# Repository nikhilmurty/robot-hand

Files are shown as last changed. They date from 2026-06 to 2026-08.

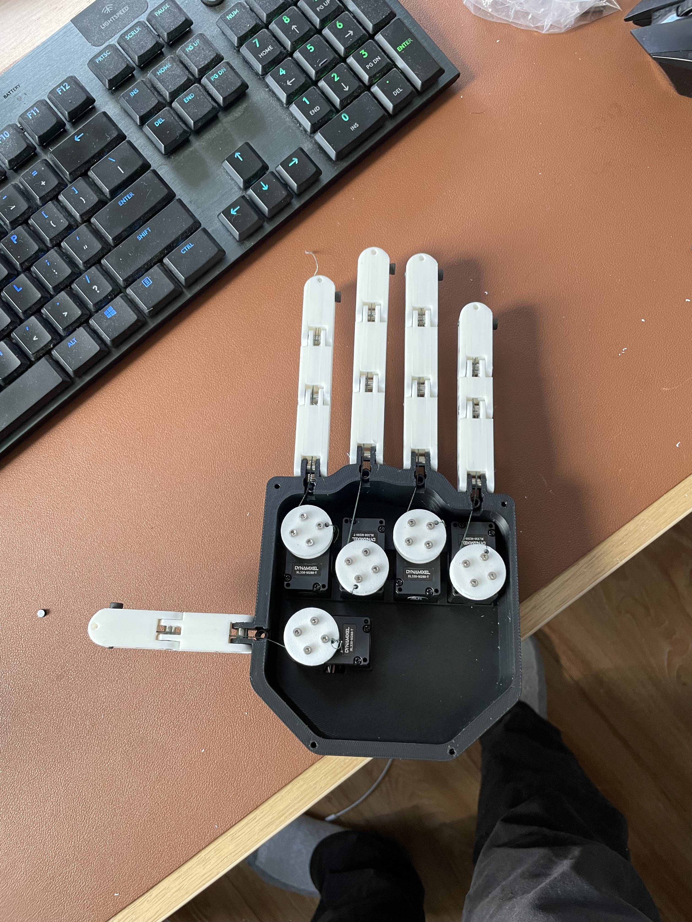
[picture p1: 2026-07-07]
hardware/IMG_2481.jpeg

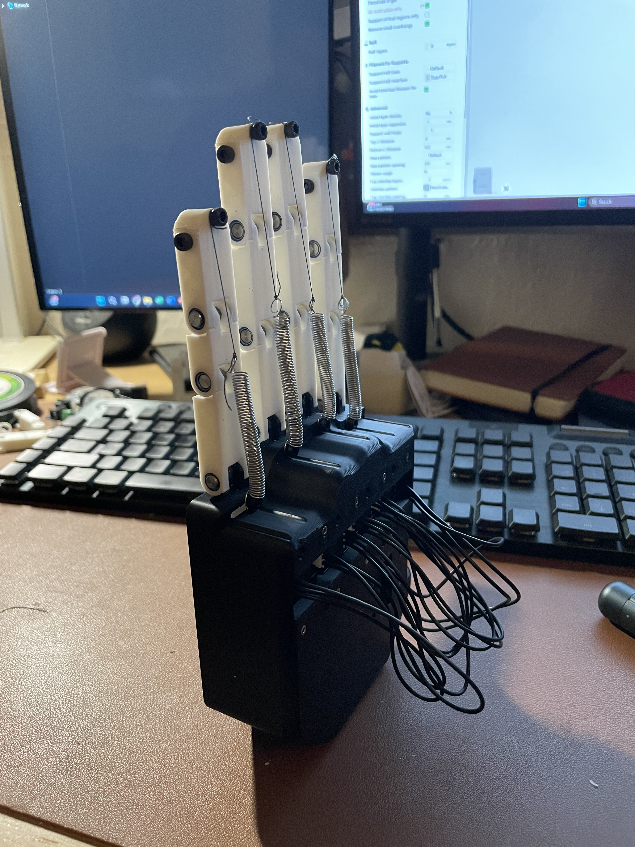
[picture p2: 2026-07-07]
hardware/IMG_2484.jpeg

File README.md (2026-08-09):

# Robot Hand

This repository contains the design, CAD models, and control software for a 5-DOF tension-driven robotic hand controlled via live webcam hand tracking.

## Quick Start Overview

To run this project, you will need to:
1. **Connect & Configure Hardware**:
   - Connect **5x Dynamixel XL-330 motors** to an **OpenRB-150** controller board (flashed with USB Passthrough / `usb_to_dxl` firmware).
   - Use **ROBOTIS DYNAMIXEL Wizard 2.0** to set baud rate to `57600` and assign motor IDs `1` (Pinky), `2` (Ring), `3` (Middle), `4` (Pointer), `5` (Thumb).
   - For detailed assembly instructions, see [hardware/README.md](hardware/README.md).

2. **Configure & Run Software**:
   - Install Python dependencies (`uv sync` or `pip install -r ...`).
   - Verify/update the serial port (`DEVICENAME`) in `software/hand_controller.py` (e.g. `COM7`, `/dev/ttyACM0`, or `/dev/tty.usbmodem*`).
   - Run the main capture script:
     ```bash
     uv run python software/finger_capture.py
     ```
   - For detailed setup, auto-tensioning overview, and software architecture, see [software/README.md](software/README.md).

## Repository Structure

- **[hardware/](hardware/README.md)**: 3D CAD files (STEP, 3MF), bill of materials, Onshape link, and hardware assembly guide. Licensed under CERN OHL v2 Permissive.
- **[software/](software/README.md)**: Python scripts for MediaPipe hand tracking (`finger_capture.py`) and Dynamixel servo control (`hand_controller.py`).

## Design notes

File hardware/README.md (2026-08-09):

# Hardware

This folder contains all the 3D design and print files for the robot hand and fingers. View the full 3D assembly on [Onshape](https://cad.onshape.com/documents/e974f0bc1062bd7b6ade647d/w/e4fd7f55056d36383327a202/e/fd9bded8c1b01162ac553002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).

## Parts & Bill of Materials

To build the hardware setup, you will need:

- **5x Dynamixel XL-330 motors**
- **1x ROBOTIS OpenRB-150 controller board** (serves as the USB-to-Dynamixel communication bridge)
- **1x USB-C Cable** (to connect OpenRB-150 to your host PC)
- **1x 5V Power Supply / Terminal block** (to power the Dynamixel motors via the OpenRB-150 board)
- **1x USB Camera / Webcam** (for hand tracking)
- **30x Bearings** (5mm ID, 8mm OD, e.g. MR85-2RS)
- **15x Dowel Pins** (M5 x 14mm)
- **Durable Cable / String** (e.g. 40 lbs braided fishing line for tendon control)
- **5x Springs** (0.5 x 5.5 x 35.5 mm for finger return tensioning)
- **Assorted M2 and M3 Screws and nuts** (I bought sets of these on amazon)
- **M2 and M3 Tap** (M2 for tapping holes in the dynamixels and M3 for the hand)

---

## Hardware Configuration & Wiring

### 1. OpenRB-150 Controller Board
- Connect the **OpenRB-150** to your computer via USB-C.
- Ensure the OpenRB-150 is flashed with **USB Passthrough firmware** (such as `usb_to_dxl` from the OpenRB-150 / DYNAMIXEL library in Arduino IDE) so it functions as a serial bridge between your computer and the servos.

### 2. Dynamixel Motor ID & Baud Rate Configuration
Use **ROBOTIS DYNAMIXEL Wizard 2.0** to assign IDs and set the baud rate before assembling:
- **Baud Rate**: `57600` (all motors must match)
- **Motor IDs**:
  - `ID 1`: Pinky Finger
  - `ID 2`: Ring Finger
  - `ID 3`: Middle Finger
  - `ID 4`: Pointer (Index) Finger
  - `ID 5`: Thumb

### 3. Assembly & Wiring
- Daisy-chain or plug all 5 Dynamixel XL-330 motors into the TTL 3-pin ports on the OpenRB-150.
- Mount the motors to the spools in the main palm assembly.
- Route string through finger joint channels and secure to tensioning springs as detailed in the Onshape model.

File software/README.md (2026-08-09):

# Software

This directory contains the Python software to control the 5-DOF tension-driven robotic hand using live webcam hand landmark tracking.

## Prerequisites

### 1. Hardware Requirements
- **Webcam**: Standard USB camera connected to your host PC.
- **OpenRB-150 Controller Board**: Connected via USB and configured with USB passthrough firmware (`usb_to_dxl`).
- **5x Dynamixel XL-330 Motors**: Connected to the OpenRB-150 board and configured as follows:
  - **Baudrate**: `57600`
  - **IDs**: 1 (Pinky), 2 (Ring), 3 (Middle), 4 (Pointer), 5 (Thumb)

### 2. Software Requirements
- **Python**: Version `3.12+`
- **Dependencies**:
  - `dynamixel-sdk`
  - `mediapipe`
  - `opencv-python`
  - `numpy`

---

## Installation & Setup

1. **Install Dependencies** using `uv` (recommended) or `pip`:
   ```bash
   uv sync
   ```
   *Alternatively, using standard `pip`:*
   ```bash
   pip install dynamixel-sdk mediapipe opencv-python numpy
   ```

2. **Identify Your Serial Port**:
   Check which port the OpenRB-150 is mounted on:
   - **Windows**: `COM3`, `COM7`, etc.
   - **macOS**: `/dev/tty.usbmodem*` or `/dev/cu.usbmodem*`
   - **Linux**: `/dev/ttyACM0` or `/dev/ttyUSB0`

3. **Configure the Serial Port**:
   In `software/hand_controller.py`, ensure the default `DEVICENAME` matches your system's serial port:
   ```python
   # Example in software/hand_controller.py:
   def __init__(self, DEVICENAME='COM7'): # Change 'COM7' to your device port (e.g. '/dev/ttyACM0')
   ```

---

## How to Run

Run `finger_capture.py` to start the hand tracking and control system:

```bash
uv run python software/finger_capture.py
```
*(or `python software/finger_capture.py` if using standard Python virtual environment)*

---

## What Happens When Running `finger_capture.py`

1. **Camera & Landmarker Setup**: Initializes OpenCV video capture from webcam (Device 0) and loads the MediaPipe `hand_landmarker.task` model.
2. **Auto-Tensioning Sequence**: 
   - `HandController` initializes the OpenRB-150 connection.
   - Executes `auto_tension()` across all 5 Dynamixels (IDs 1 through 5).
   - Servos pull tension until current limits are detected to establish the open/closed position bounds for each finger.
3. **Live Hand Tracking & Motor Control**:
   - A thread reads frames from the webcam and runs MediaPipe hand landmark detection.
   - A second thread extracts 3D joint vectors for each finger (thumb, pointer, middle, ring, pinky) to compute flexion angles.
   - Angles are transformed into motor target positions and synced over the serial port to the OpenRB-150 board.
4. **Display & Exit**:
   - Displays a live video feed window with skeleton landmark overlays.
   - Press **`q`** while focused on the video window to quit, disable motor torque, and safely close the serial connection.

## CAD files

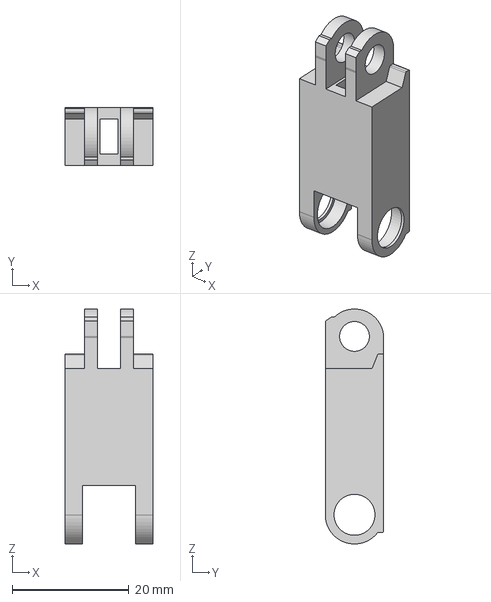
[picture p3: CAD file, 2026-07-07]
hardware/ Index/Index - Middle_Segment.step
15.0 x 10.0 x 40.2 mm

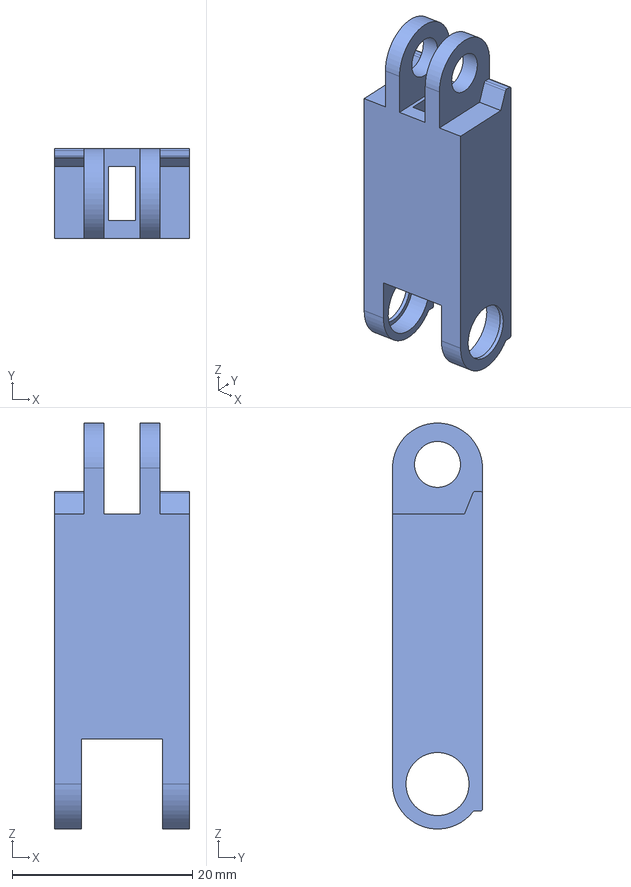
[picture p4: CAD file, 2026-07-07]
hardware/Middle/Middle - Bottom_Segment.step
15.0 x 10.0 x 45.1 mm

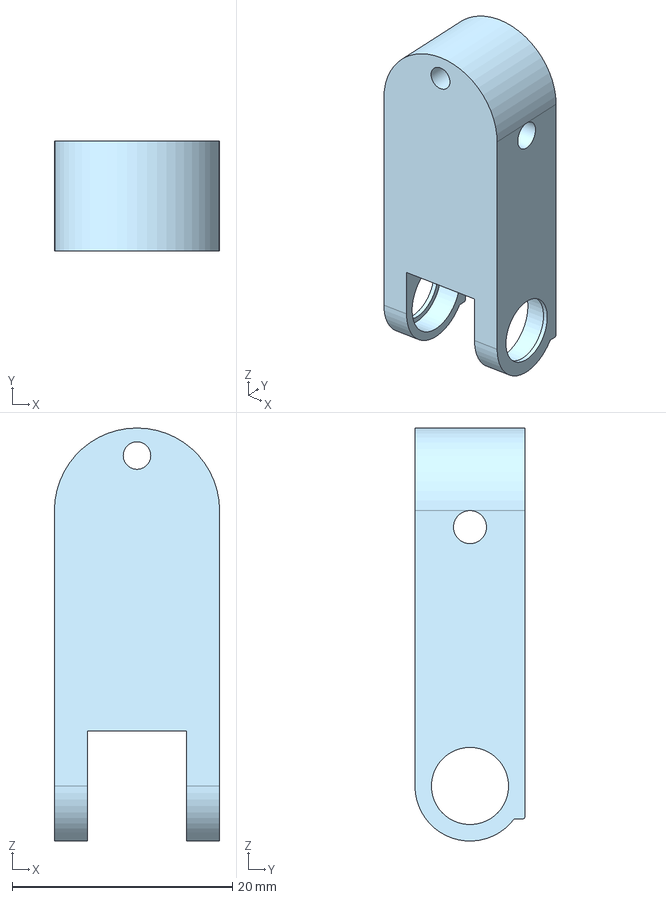
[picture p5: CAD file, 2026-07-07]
hardware/Ring/Ring - Top_Segment.step
15.0 x 10.0 x 37.5 mm

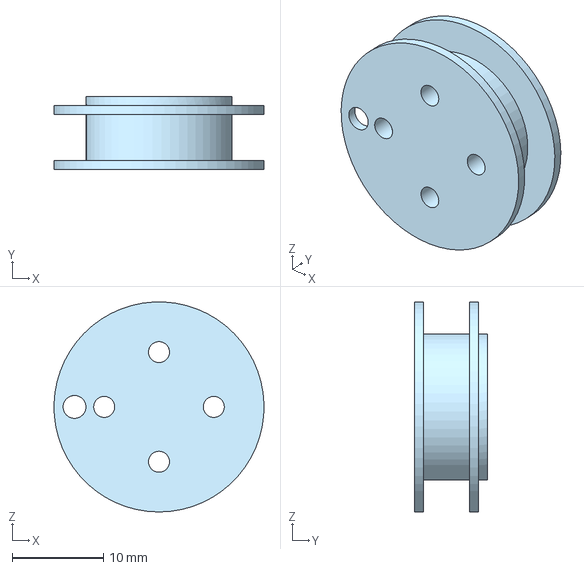
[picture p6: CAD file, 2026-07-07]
hardware/Spool.step
23.0 x 8.00 x 23.0 mm

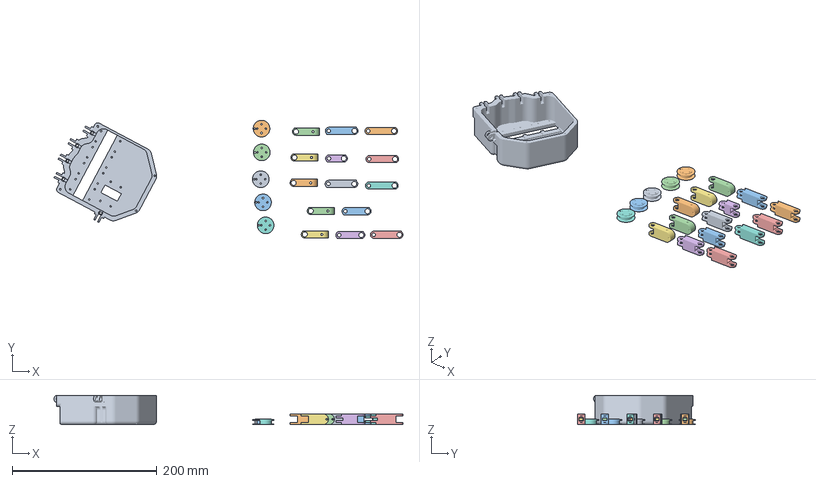
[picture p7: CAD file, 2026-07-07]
hardware/Hand.3mf
481.7 x 163.4 x 40.5 mm
Palm - Palm.step
Middle - Bottom_Segment.step
Middle - Middle_Segment.step
Middle - Top_Segment.step
Pinky - Bottom_Segment.step
Pinky - Middle_Segment.step
Pinky - Top_Segment.step
Ring - Bottom_Segment.step
Ring - Middle_Segment.step
Ring - Top_Segment.step
Thumb - Middle_Segment.step
Thumb - Top_Segment.step
Index - Bottom_Segment.step
Index - Middle_Segment.step
Index - Top_Segment.step
Spool.step x 5

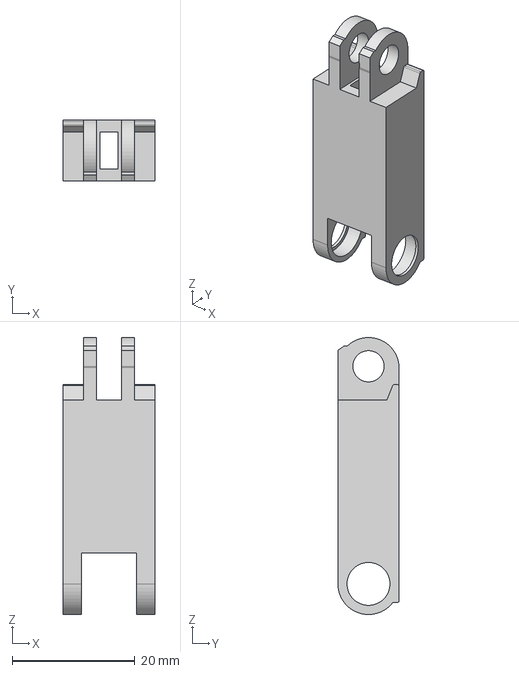
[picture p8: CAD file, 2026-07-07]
hardware/Middle/Middle - Middle_Segment.step
15.0 x 10.0 x 45.2 mm

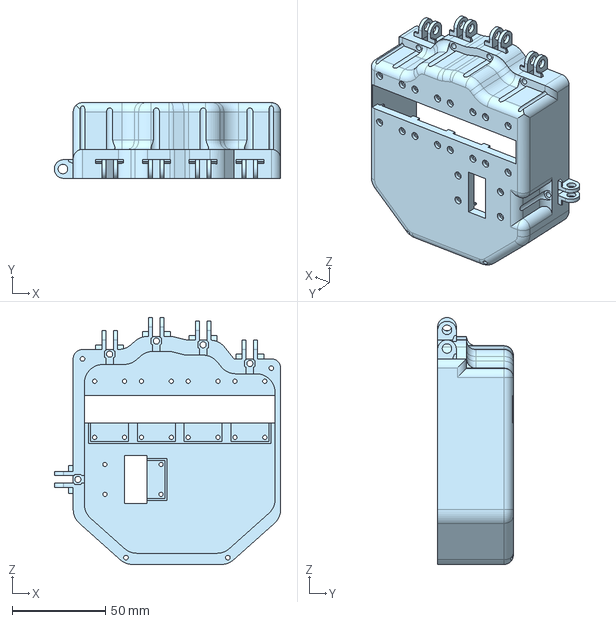
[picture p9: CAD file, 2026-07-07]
hardware/Palm - Palm.step
121.1 x 40.5 x 132.1 mm

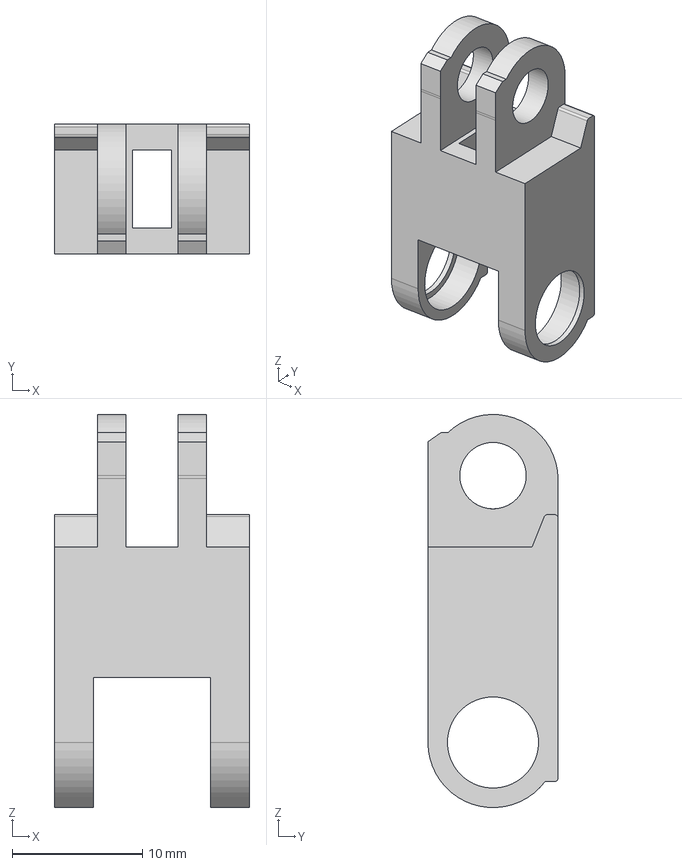
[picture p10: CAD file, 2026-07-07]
hardware/Pinky/Pinky - Middle_Segment.step
15.0 x 10.0 x 30.2 mm

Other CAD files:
hardware/Pinky/Pinky - Bottom_Segment.step
hardware/Thumb/Thumb - Top_Segment.step
hardware/ Index/Index - Top_Segment.step
hardware/Pinky/Pinky - Top_Segment.step
hardware/Ring/Ring - Bottom_Segment.step
hardware/Thumb/Thumb - Middle_Segment.step
hardware/ Index/Index - Bottom_Segment.step
hardware/Middle/Middle - Top_Segment.step
hardware/Ring/Ring - Middle_Segment.step

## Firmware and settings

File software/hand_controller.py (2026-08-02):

"""Hand Controller Class
Handles control of 5 dynamixel motors that control the fingers on a tension driven robotic hand
"""
from dynamixel_sdk import *
import time
import threading

class Finger:
    def __init__(self, name, motor_id, min = 0, max = 120):
        self.name = name
        self.motor_id = motor_id
        self.open_pos = 0
        self.closed_pos = 0

        self.min_angle = min
        self.max_angle = max

        self.actual_pos = 0.0
        self.actual_current = 0.0
        self.actual_velocity = 0.0

        self.target_pos = 0


    def calculate_motor_angle(self, finger_angle):
        # Clamp input to safe bounds
        clamped_angle = max(self.min_angle, min(finger_angle, self.max_angle))
        
        # Map from [min, max] -> [closed, open]
        self.target_pos = self.open_pos + (clamped_angle - self.min_angle) * (self.closed_pos - self.open_pos) / (self.max_angle - self.min_angle)
        return int(self.target_pos)
    
    def update_values(self, pos, current, velocity):
        self.actual_pos = pos
        self.actual_current = current
        self.actual_velocity = velocity


class HandController:
    ADDR_TORQUE_ENABLE          = 64
    ADDR_OPERATING_MODE         = 11          
    ADDR_TARGET_POSITION        = 116
    ADDR_GOAL_CURRENT           = 102
    LEN_GOAL_POSITION           = 4

    ADDR_ACTUAL_POSITION        = 132
    ADDR_ACTUAL_CURRENT         = 126
    ADDR_ACTUAL_VELOCITY        = 128

    CURRENT_POSITION_OPERATION  = 5         #Current based position
    MAX_CURRENT                 = 300       #current cap until backdrivable
    TENSION_CURRENT             = 20

    PROTOCOL_VERSION            = 2.0
    DXL_ID                      = 1
    BAUDRATE                    = 57600

    THUMB                       = 5
    POINTER                     = 4
    MIDDLE                      = 3
    RING                        = 2
    PINKY                       = 1
    MOTOR_IDS                   = [1,2,3,4,5]


    def __init__(self, DEVICENAME ='COM7'):
        self.portHandler = PortHandler(DEVICENAME)
        self.packetHandler = PacketHandler(self.PROTOCOL_VERSION)

        if not self.portHandler.openPort() or not self.portHandler.setBaudRate(self.BAUDRATE):
            print("Failed to open port or set baudrate. Check your DEVICENAME!")
            quit()

        #create the hand
        self.hand = {
            "THUMB"   : Finger("THUMB", self.THUMB, 0, 75),
            "POINTER" : Finger("POINTER", self.POINTER, 0, 120),
            "MIDDLE"  : Finger("MIDDLE", self.MIDDLE, 0, 120),
            "RING"    : Finger("RING", self.RING, 0, 120),
            "PINKY"   : Finger("PINKY", self.PINKY, 0, 120)
        }

        self.auto_tension()
        print("Finished tensioning")

        self.groupSyncWrite = GroupSyncWrite(self.portHandler, self.packetHandler, self.ADDR_TARGET_POSITION, 4)
        self.groupSyncRead  = GroupSyncRead(self.portHandler, self.packetHandler, self.ADDR_ACTUAL_CURRENT, 10)

        for finger in self.hand.values():
            self.groupSyncRead.addParam(finger.motor_id)

        self.hand_thread = threading.Thread(target=self.run, daemon=True)

    def close_port(self):
        for finger in self.hand.values():
            self.disable(finger.motor_id)

        self.portHandler.closePort()

    def enable(self, motor):
        self.packetHandler.write1ByteTxRx(self.portHandler, motor, self.ADDR_TORQUE_ENABLE, 1)
        print(f"Torque enabled on joint #{motor}")

    def disable(self, motor):
        self.packetHandler.write1ByteTxRx(self.portHandler, motor, self.ADDR_TORQUE_ENABLE, 0)
        print(f"Torque disabled on joint #{motor}")

    def read_hand(self):
        """Reads values coming from dynamixels, saves to the motor classes
        """

        dxl_comm_result = self.groupSyncRead.txRxPacket()
        if dxl_comm_result != COMM_SUCCESS:
            print(f"Sync read failed: {self.packetHandler.getTxRxResult(dxl_comm_result)}")
            return

        for finger in self.hand.values():
            motor = finger.motor_id

            if self.groupSyncRead.isAvailable(motor, self.ADDR_ACTUAL_POSITION, 4):
                # Retrieve the 4-byte position data
                curr = self.groupSyncRead.getData(motor, self.ADDR_ACTUAL_CURRENT, 2)
                if curr > 32767:
                    curr -= 65536

                vel = self.groupSyncRead.getData(motor, self.ADDR_ACTUAL_VELOCITY, 4)
                if vel > 2147483647:
                    vel -= 4294967296

                pos = self.groupSyncRead.getData(motor, self.ADDR_ACTUAL_POSITION, 4)
                # Convert from unsigned to signed 32-bit integer
                if pos > 2147483647:
                    pos -= 4294967296
                
                finger.update_values(pos, curr, vel)
            else:
                print(f"[ID:{motor}] groupSyncRead data not available")

    def write_hand(self):
        """writes values to hands
        """

        self.groupSyncWrite.clearParam()

        for finger in self.hand.values():
            motor  = finger.motor_id
            target = int(finger.target_pos)

            dxl_addparam_result = self.groupSyncWrite.addParam(motor, target.to_bytes(4, 'little', signed=True))

            if not dxl_addparam_result:
                print(f"addParam failed for joint #{motor}")
                return
        

        dxl_comm_result = self.groupSyncWrite.txPacket()
        if dxl_comm_result != COMM_SUCCESS:
            print(f"Sync write failed: {self.packetHandler.getTxRxResult(dxl_comm_result)}")
            return

    def start(self):
        self.is_running = True
        self.hand_thread.start()

    def stop(self):
        self.is_running = False
        self.hand_thread.join(timeout=2.0)
    def run(self):
        try:
            while self.is_running:
                self.read_hand()
                self.write_hand()

                time.sleep(0.01)

        except Exception as e:
            print(f"Error in main loop: {e}")

        finally:
            self.close_port()
                



    def auto_tension(self):
        """Auto tensions every finger and gets max and min positions
        """

        for name,finger in self.hand.items():
            motor = finger.motor_id

            tensioned = False
            maxxed = False
            
            #set operating mode to current based position
            self.packetHandler.write1ByteTxRx(self.portHandler, motor , self.ADDR_OPERATING_MODE, self.CURRENT_POSITION_OPERATION)

            #Start Motor
            self.enable(motor)

            #set goal current to tension and move until tensioned
            self.packetHandler.write2ByteTxRx(self.portHandler, motor , self.ADDR_GOAL_CURRENT, self.TENSION_CURRENT)

            start_pos, _, _ = self.packetHandler.read4ByteTxRx(self.portHandler, motor, self.ADDR_ACTUAL_POSITION)
            if start_pos > 2147483647:
                start_pos -= 4294967296
            tension_pos = start_pos + 3000
            self.packetHandler.write4ByteTxRx(self.portHandler, motor , self.ADDR_TARGET_POSITION, tension_pos)

            #read position and current until it doesnt change
            while not tensioned:
                pos, dxl_comm_result, dxl_error = self.packetHandler.read4ByteTxRx(self.portHandler, motor, self.ADDR_ACTUAL_POSITION)
                if pos > 2147483647:
                    pos -= 4294967296
                curr, _, _ =  self.packetHandler.read2ByteTxRx(self.portHandler, motor, self.ADDR_ACTUAL_CURRENT)

                if curr > 32767:
                    curr -= 65536
                curr = abs(curr)

                if curr >= self.TENSION_CURRENT:
                    finger.open_pos = pos           #set open pos to tensioned value
                    tensioned = True
                
                time.sleep(0.1)
            
            #To get max position, we just need to set the current to the max current threshold
            prev_pos = 0
            self.packetHandler.write2ByteTxRx(self.portHandler, motor , self.ADDR_GOAL_CURRENT, self.MAX_CURRENT)

            while not maxxed:
                #will not hit the max threshold so we need to just keep moving until motion stops
                pos, dxl_comm_result, dxl_error = self.packetHandler.read4ByteTxRx(self.portHandler, motor, self.ADDR_ACTUAL_POSITION)
                if pos > 2147483647:
                    pos -= 4294967296

                if pos - prev_pos <= 0:
                    #limit has been hit
                    finger.closed_pos = pos
                    maxxed = True
                
                prev_pos = pos
                time.sleep(0.1)
                

            #move finger to open position
            finger.target_pos = finger.open_pos
            self.setPosition(motor, finger.open_pos)
            print(f"{name} is tensioned!")


    def setPosition(self, motor, position):
        """transmits position data to the motor

        Args:
            motor (int): motor number in the chain
            position (int): position of the motor in degrees
        """
        self.packetHandler.write4ByteTxRx(self.portHandler, motor, self.ADDR_TARGET_POSITION, position)

    def setHandPosition(self,positions):
        """Sets the positions of each of the fingers

        Args:
            positions (array of ints): an array containing all the joints starting from thumb (motor enumeration starts at 1)
        """
        for i, finger in enumerate(self.hand.values()):
            position = finger.calculate_motor_angle(positions[i])



if __name__ == "__main__":
    motor = HandController()
    i = 0
    motor.close_port()
    print("Port closed")

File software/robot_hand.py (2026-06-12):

from mediapipe.tasks.python.vision import HandLandmarker, HandLandmarkerResult
import mediapipe as mp
from mediapipe.tasks import python 
from mediapipe.tasks.python import vision
import cv2
import threading
import time
import os
import numpy as np

class FingerCapture:
    modelpath = os.path.join(os.path.dirname(os.path.abspath(__file__)), "hand_landmarker.task")
    

    def __init__(self, num_hands):
        self.isRunning = False
        self.trackingThread = threading.Thread(target=self.processing_callback, daemon=True)
        self.frameLock = threading.Lock()
        self.currentFrame = None
        self.result_lock = threading.Lock()
        self.result = None

        self.cap = cv2.VideoCapture(1)

        # set up hand model
        self.HandLandmarker = mp.tasks.vision.HandLandmarker
        BaseOptions = mp.tasks.BaseOptions
        HandLandmarkerOptions = mp.tasks.vision.HandLandmarkerOptions
        self.HandLandmarkerResult = mp.tasks.vision.HandLandmarkerResult
        VisionRunningMode = mp.tasks.vision.RunningMode

        self.LandmarkerOptions = HandLandmarkerOptions(
            base_options=BaseOptions(model_asset_path= self.modelpath),
            running_mode=VisionRunningMode.LIVE_STREAM,
            result_callback=self.print_result)
        
    def print_result(self, result: HandLandmarkerResult, output_image: mp.Image, timestamp_ms: int):
        with self.result_lock:
            self.result = result

    def start(self):
        self.isRunning = True
        self.trackingThread.start()
        self.display_callback()

    
    def processing_callback(self):
        try:
            with self.HandLandmarker.create_from_options(self.LandmarkerOptions) as landmarker:
                consecutive_failures = 0
                while self.isRunning:
                    ret, frame = self.cap.read()
                    
                    #watch to see if camera isn't reading
                    if not ret or frame is None or frame.size == 0:
                        consecutive_failures += 1
                        if consecutive_failures % 10 == 1:
                            print("Waiting for camera feed to initialize...")
                        time.sleep(0.1)
                        if consecutive_failures > 50:
                            print("Error: Could not read frame from camera. Exiting.")
                            break
                        continue
                    consecutive_failures = 0
                    
                    # lock thread and copy over current frame back to main
                    with self.frameLock:
                        self.currentFrame = frame.copy()

                    #convert image to mediapipe image
                    rgb_img = cv2.cvtColor(frame, cv2.COLOR_BGR2RGB)
                    mp_image = mp.Image(image_format=mp.ImageFormat.SRGB, data=rgb_img)

                    #detect landmarks using camera
                    timestamp = int(time.time()*1000)
                    landmarker.detect_async(mp_image, timestamp)

        except Exception as e: 
            print("error in processing, exiting")
            self.isRunning = False

    def draw_landmarks_on_image(self, annotated_image, detection_result):
        height, width, _ = annotated_image.shape

        # Define hand connections: (start_index, end_index)
        connections = [
            # Thumb
            (0, 1), (1, 2), (2, 3), (3, 4),
            # Index Finger
            (0, 5), (5, 6), (6, 7), (7, 8),
            # Middle Finger
            (0, 9), (9, 10), (10, 11), (11, 12),
            # Ring Finger
            (0, 13), (13, 14), (14, 15), (15, 16),
            # Pinky
            (0, 17), (17, 18), (18, 19), (19, 20),
            # Knuckle connections (connecting MCP joints)
            (5, 9), (9, 13), (13, 17)
        ]

        if detection_result.hand_landmarks:
            for hand_landmarks in detection_result.hand_landmarks:
                # Convert normalized coordinates to pixel coordinates
                coords = []
                for landmark in hand_landmarks:
                    cx = int(landmark.x * width)
                    cy = int(landmark.y * height)
                    coords.append((cx, cy))

                # Draw connection lines (Red)
                for start_idx, end_idx in connections:
                    if start_idx < len(coords) and end_idx < len(coords):
                        cv2.line(annotated_image, coords[start_idx], coords[end_idx], (0, 0, 255), 2)

                # Draw landmark points (Green)
                for coord in coords:
                    cv2.circle(annotated_image, coord, 5, (0, 255, 0), -1)

        return annotated_image

    def display_callback(self):
        try:
            while self.isRunning:
                frame = None

                # get the current frame
                with self.frameLock:
                    if self.currentFrame is not None:
                        frame = self.currentFrame.copy()

                if frame is None:
                    time.sleep(0.01)
                    continue

                # 1. Safely grab the latest data payload
                with self.result_lock:
                    latest_result = self.result
                    
                if latest_result and latest_result.hand_landmarks:
                    # Convert BGR frame to RGB, draw landmarks, and convert back
                    rgb_frame = cv2.cvtColor(frame, cv2.COLOR_BGR2RGB)
                    annotated_rgb = self.draw_landmarks_on_image(rgb_frame, latest_result)
                    frame = cv2.cvtColor(annotated_rgb, cv2.COLOR_RGB2BGR)
                    
                cv2.imshow('Video Feed', frame)

                if cv2.waitKey(1) & 0xFF == ord('q'):
                    print("Quit key pressed, stopping capture.")
                    break

        finally: 
            self.cap.release()
            cv2.destroyAllWindows()
            self.isRunning = False


if __name__ == "__main__":
    hands = FingerCapture(1)
    hands.start()

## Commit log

2026-06-12 separate threads working
2026-06-23 single finger working, needs refinement
2026-07-07 adding cad files
    [Hand.3mf, Index - Bottom_Segment.step, Index - Middle_Segment.step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]
2026-07-14 automatic tensioning working
2026-08-02 switching back to locating off of the wrist
